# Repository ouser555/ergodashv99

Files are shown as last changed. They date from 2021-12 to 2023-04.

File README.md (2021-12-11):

# ergodashv99
ergodash + v99 trackpoint moudle

pcb & case

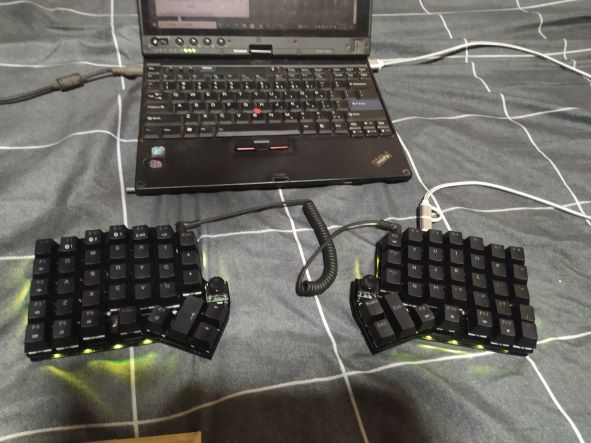
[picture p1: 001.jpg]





mp4 file demo 1: https://imgur.com/L2KnZHe

[IMAGE ALT TEXT HERE)](https://imgur.com/L2KnZHe)

mp4 file demo 2: https://imgur.com/nbIOpWw

[IMAGE ALT TEXT HERE)](https://imgur.com/nbIOpWw)

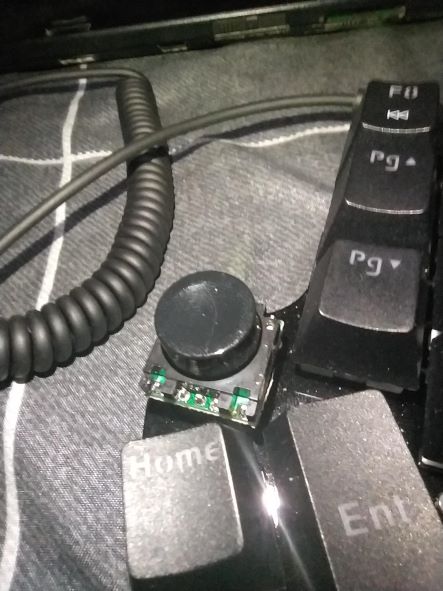
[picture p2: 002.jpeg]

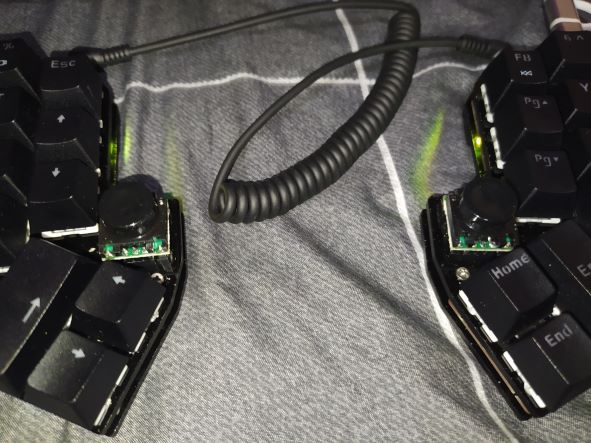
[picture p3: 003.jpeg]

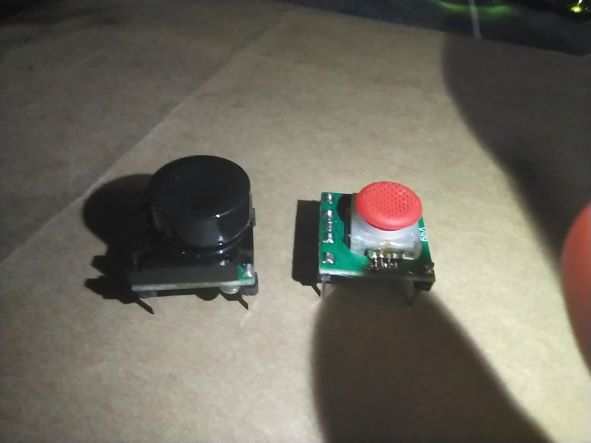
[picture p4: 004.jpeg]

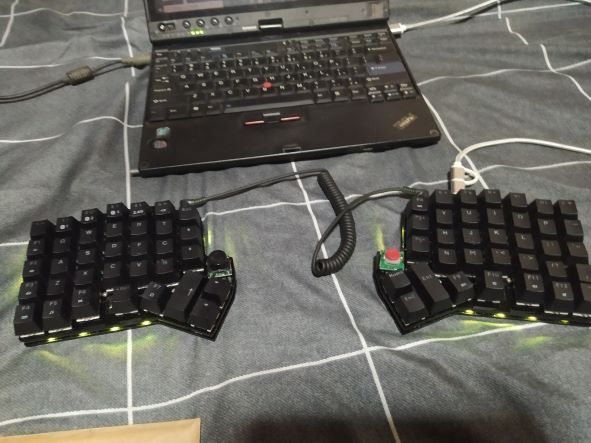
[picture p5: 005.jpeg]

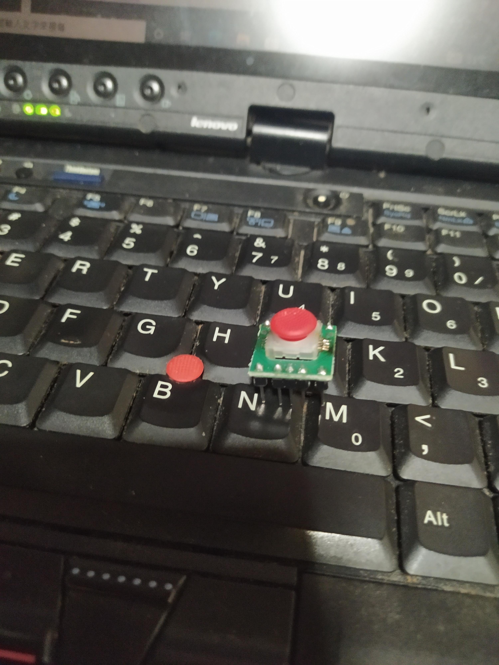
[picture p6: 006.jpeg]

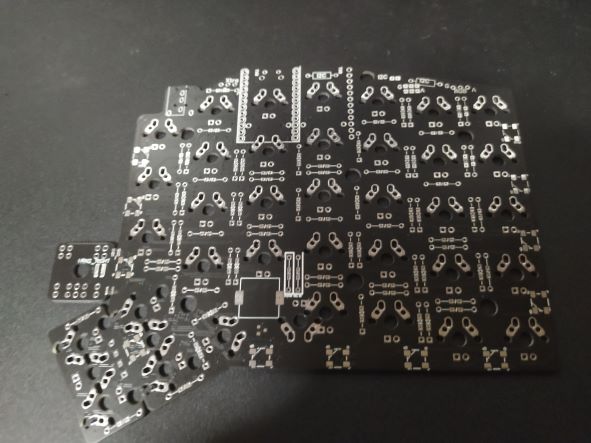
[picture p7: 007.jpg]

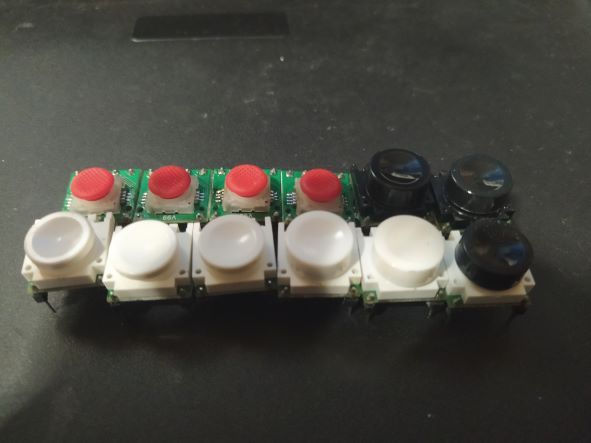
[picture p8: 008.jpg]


## 20211211 土炮增高套件

千辛萬苦找到增高套件協力廠商



組裝完成



演示

VID_20211211_083757

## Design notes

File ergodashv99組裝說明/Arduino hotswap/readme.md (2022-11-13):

## 這裡主要對熱Arduino ProMicro插拔座的安裝方式進行說明。

### 套件裡面有兩組Arduino ProMicro包，附帶三條排針，4Pin的不用理它，用不到。

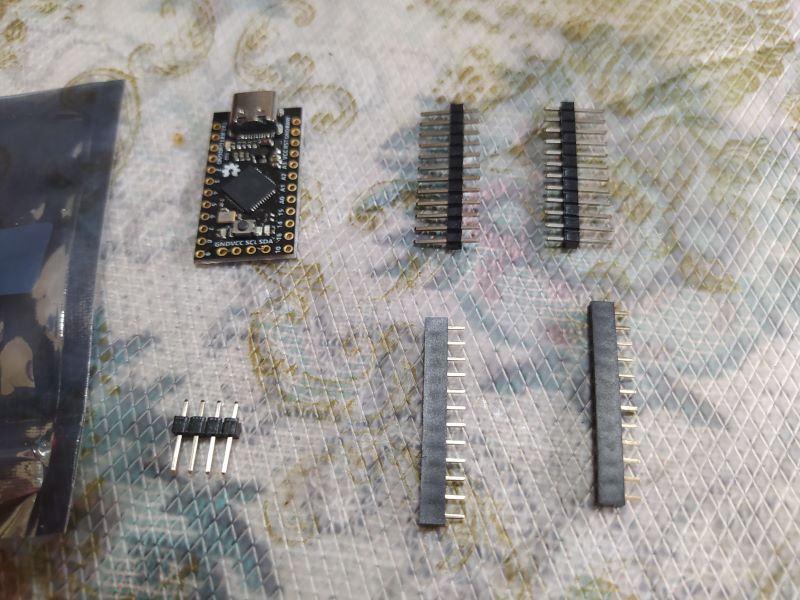
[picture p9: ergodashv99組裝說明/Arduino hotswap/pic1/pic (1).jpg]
  

  如圖所示新增了兩個12Pin的排針座，這是為了讓Arduino ProMicro可以插拔而增加的零件。
 
  這種雙面使用的PCB設計方式，以往經驗會常會有人一不留神把ProMicro焊錯了位置，
  
  導致後來的解焊困難甚至直接放棄治療，所以增加了這個零件來提高容錯率，
  
  未來要維修換軸或者是改藍牙都會更加方便。

### 要讓排針比較容易剪斷，這裡先拿尖嘴鉗把排針短的一端壓入長的那端。
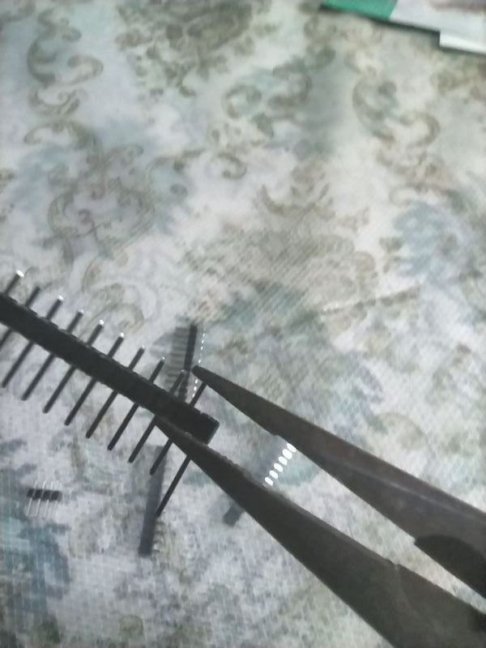
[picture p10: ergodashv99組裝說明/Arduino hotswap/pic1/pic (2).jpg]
  

### 12P壓完如圖所示。一共要壓4條。
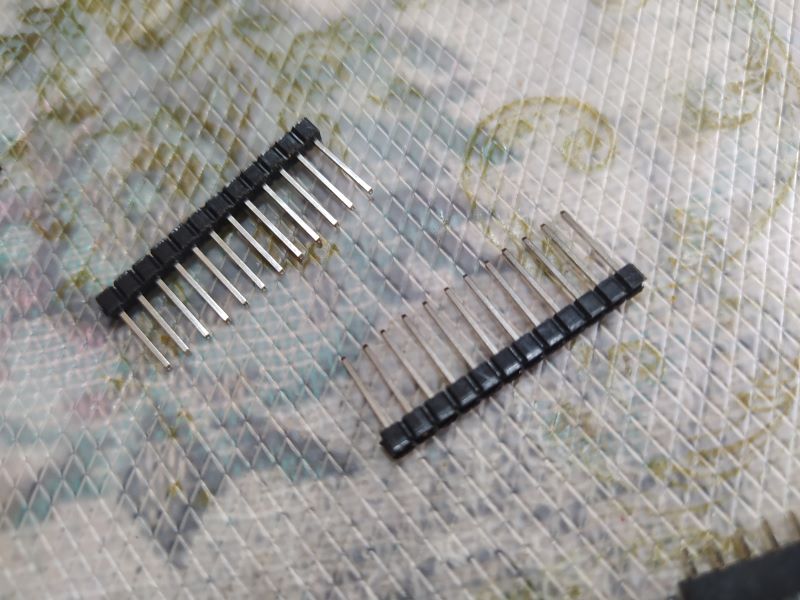
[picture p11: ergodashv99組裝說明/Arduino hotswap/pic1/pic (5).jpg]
  

### 壓好的排針先通過ProMicro後，插入排針座。
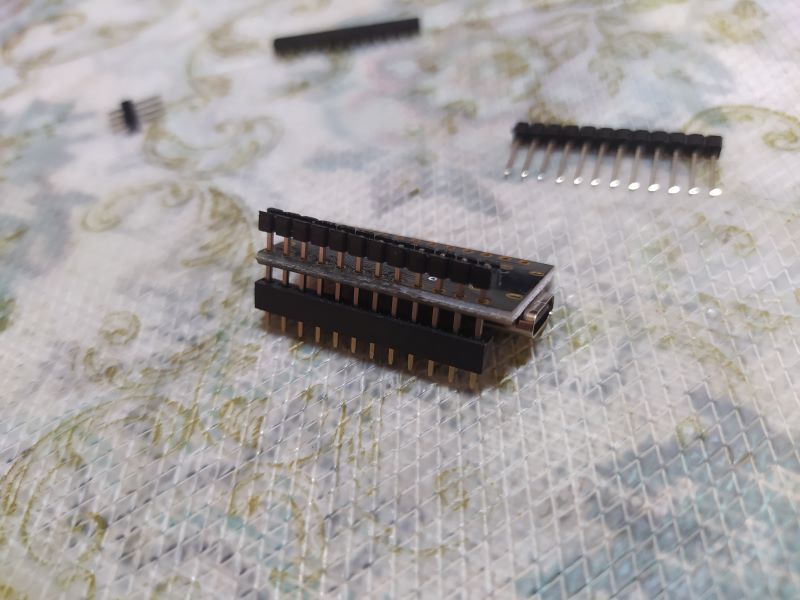
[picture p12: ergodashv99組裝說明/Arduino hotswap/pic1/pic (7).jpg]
  

### 兩邊都先插好。

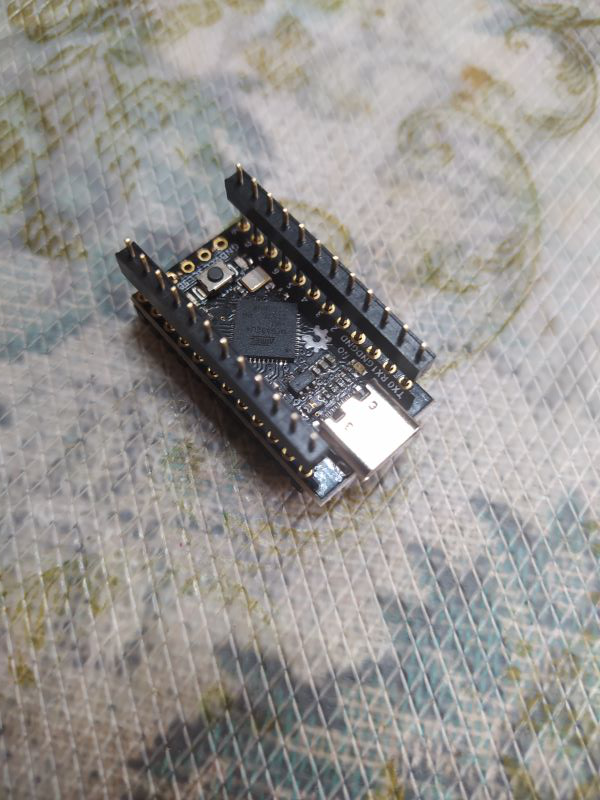
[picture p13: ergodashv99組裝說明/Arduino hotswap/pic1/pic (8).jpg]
  

### 確定鍵盤PCB的零件面，有白框的排針孔。

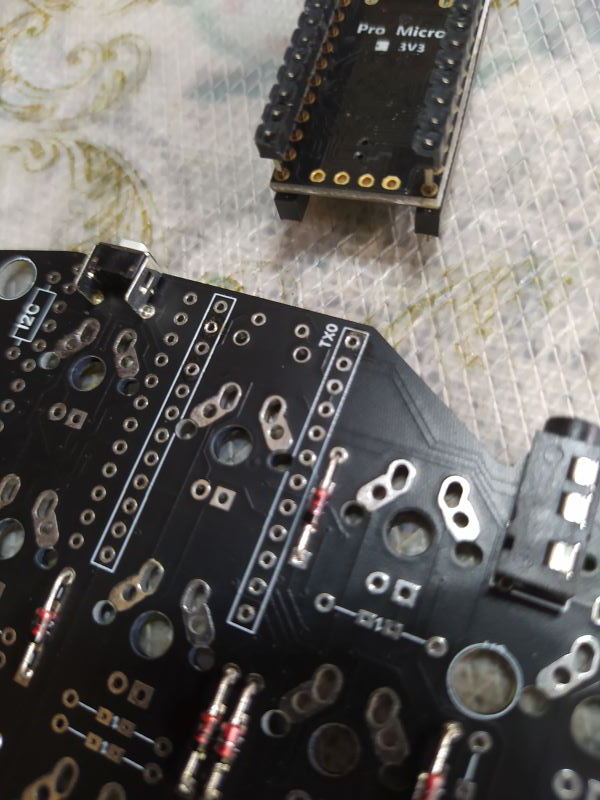
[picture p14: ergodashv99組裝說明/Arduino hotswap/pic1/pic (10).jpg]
  

### 置入，讓PCB貼住下方的排針座，使之間沒有空隙。
  如此ProMicro就成為了一個固定工具，此時先對排針座和鍵盤PCB的部分進行焊接。
  
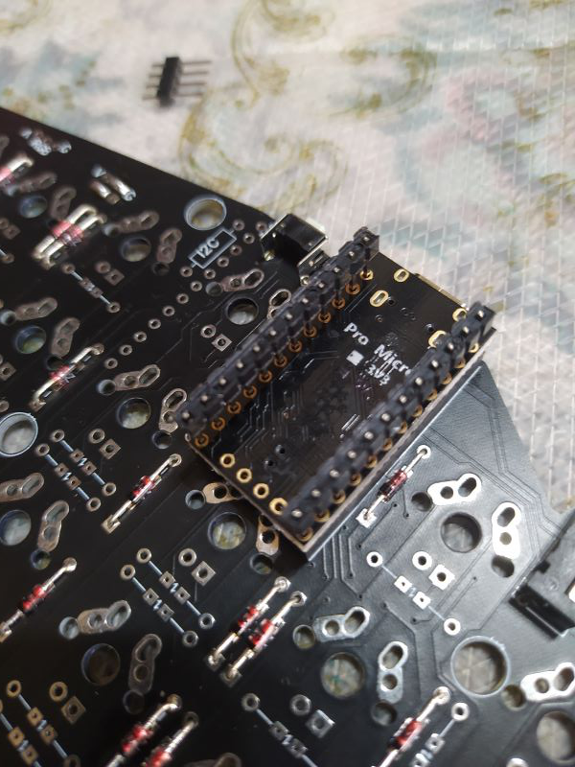
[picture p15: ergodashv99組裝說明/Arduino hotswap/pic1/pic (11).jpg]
  
  
### 焊好如圖。

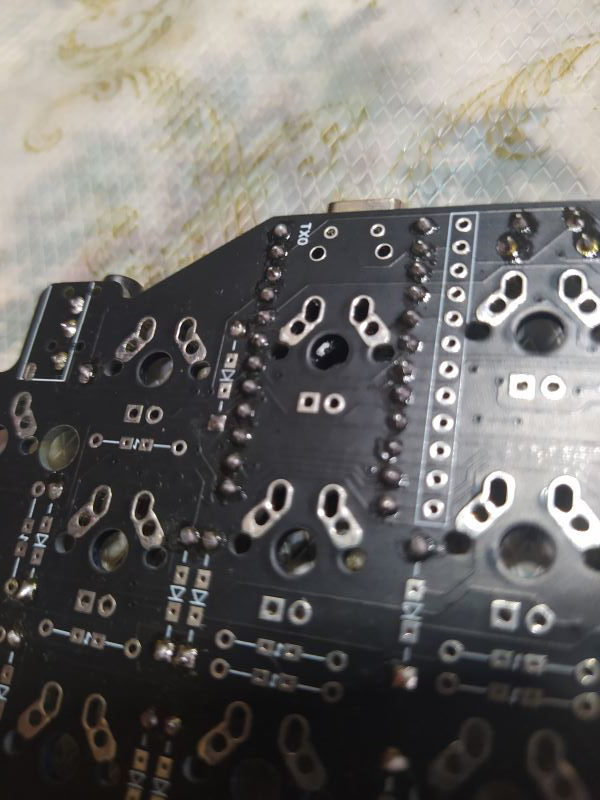
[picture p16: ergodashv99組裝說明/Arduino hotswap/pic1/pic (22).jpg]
  

### 然後就可以焊排針腳和ProMicro的部分。(先焊再剪針腳)
  如果對自己的技術有自信，為了美觀，先剪排針腳再焊接也是可以。(下面失敗案例先看完)
  
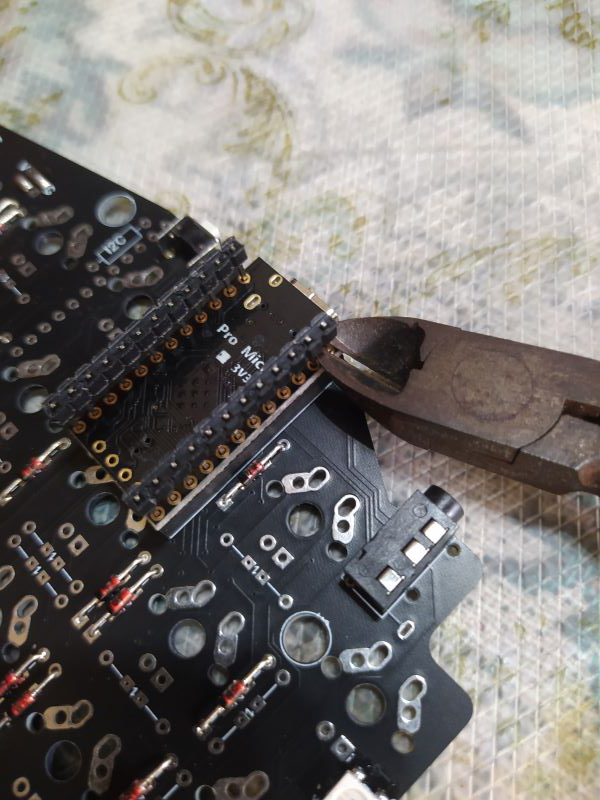
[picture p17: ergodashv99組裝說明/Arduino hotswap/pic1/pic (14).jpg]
  
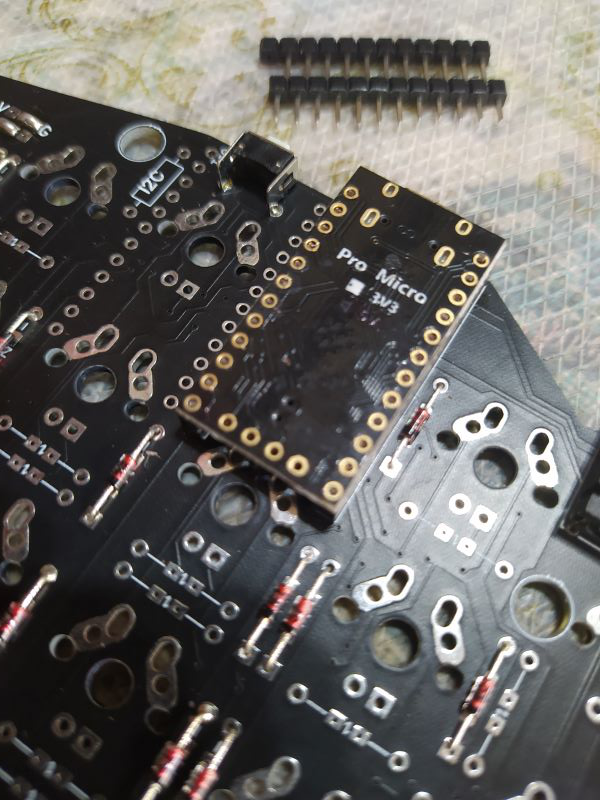
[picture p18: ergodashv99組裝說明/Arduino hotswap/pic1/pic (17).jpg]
  
  
  可以看到剪針腳時，工具或技術不好會把排針拉出來，有的針腳會掉到排針座外面，
  
  後來又必須要重新調整。所以請自行斟酌要先焊或是先剪。
  
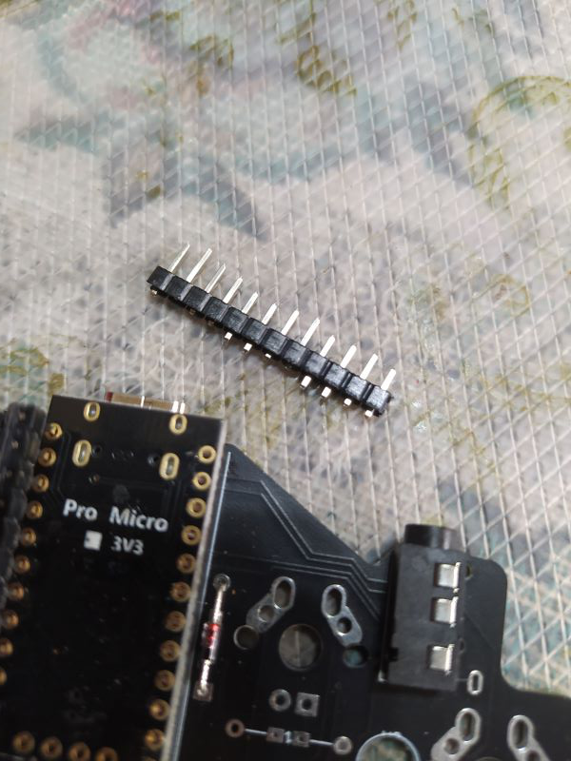
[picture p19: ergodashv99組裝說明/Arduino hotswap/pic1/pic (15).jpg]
  

### 焊好如圖。

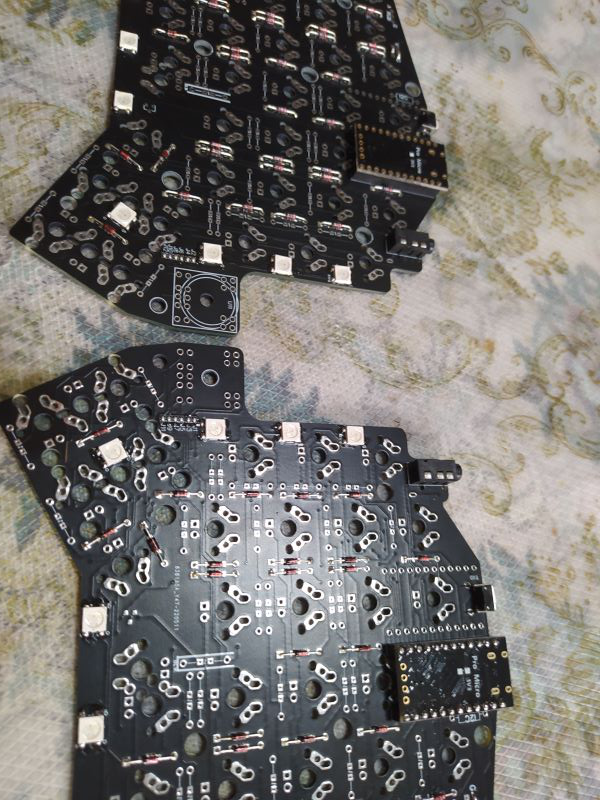
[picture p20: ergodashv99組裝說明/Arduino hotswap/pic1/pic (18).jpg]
  
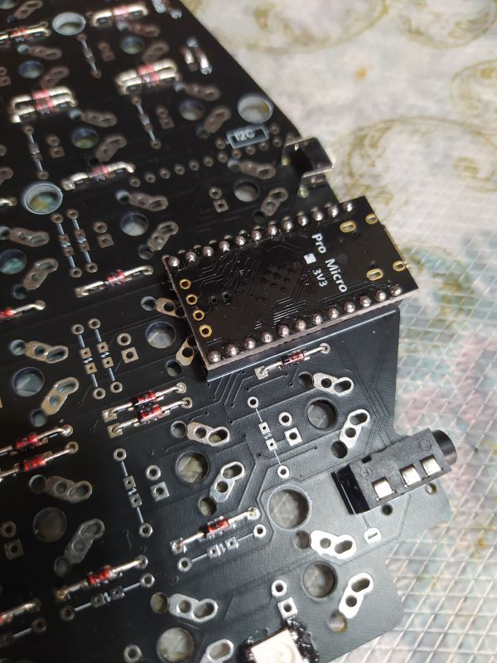
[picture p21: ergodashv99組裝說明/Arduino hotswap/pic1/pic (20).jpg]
  
  
### 拔下來看看，沒問題再插回去。

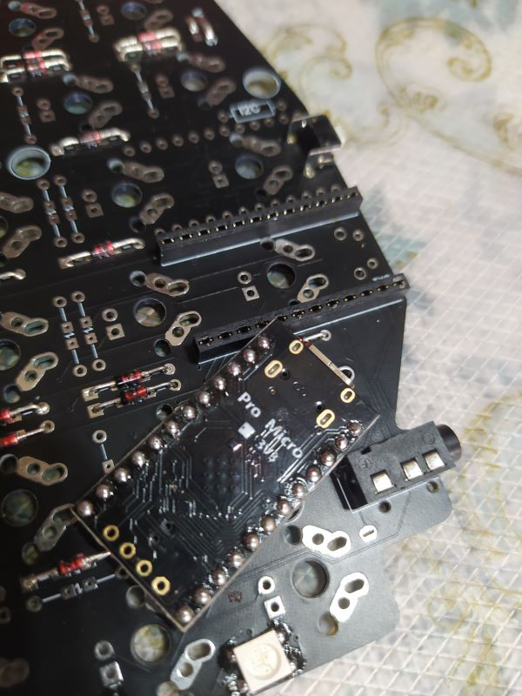
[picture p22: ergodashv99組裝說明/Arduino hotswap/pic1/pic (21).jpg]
  

### 熱插拔元件都是用彈片去夾住針腳的方式設計，為了保持它功能的穩定性，建議不要進行頻繁插拔的動作。

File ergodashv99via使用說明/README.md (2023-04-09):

## ergodashv99 via configuration使用說明

* 最近變動說明
  * 20230409
    * VIA configuartion更新到了3.0.0版。
    * VIA網頁版都會用最新版本，所以有一天網頁版的custom keycode突然不能用了，那就是它對custom keycode最對應的更新了，
      此時若有急用可以先下載程式版的3.0.0應急。  

* 如果要讓trackpoint更容易使用，windows打開設定，滑鼠頁面，設定，這裡提供測試過比較好的參數，使用者也可以依需求自行調整。
  
  滑鼠速度:游標速度:6
  
  滾輪速度:選擇一次要捲動的行數:1(滾輪用這個會比較平滑)
  
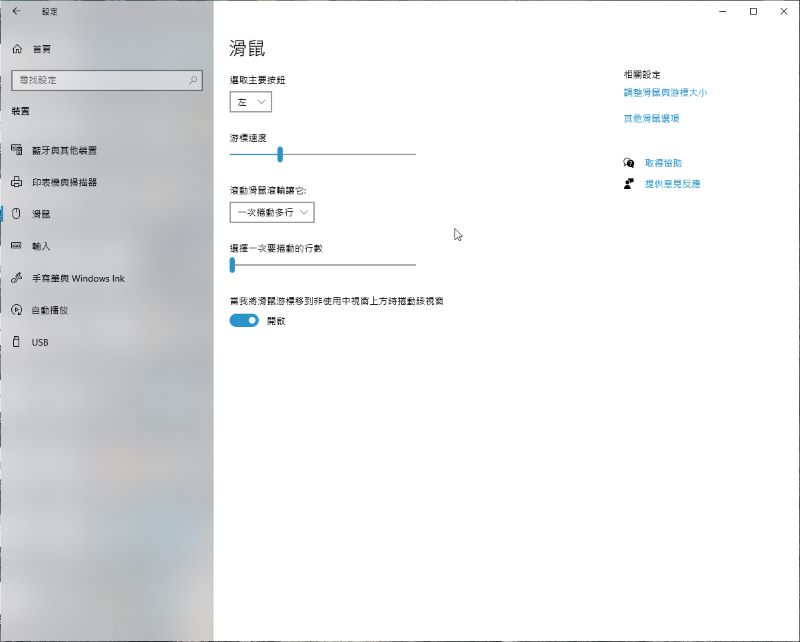
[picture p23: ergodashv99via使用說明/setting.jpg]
  

* 先到 https://caniusevia.com/ 選擇download via下載via configuration。(網頁連結拿掉了)
  * 換這個 https://github.com/the-via/releases/releases/tag/v2.0.5
  * 或更新的 https://github.com/the-via/releases/releases/tag/v2.1.0
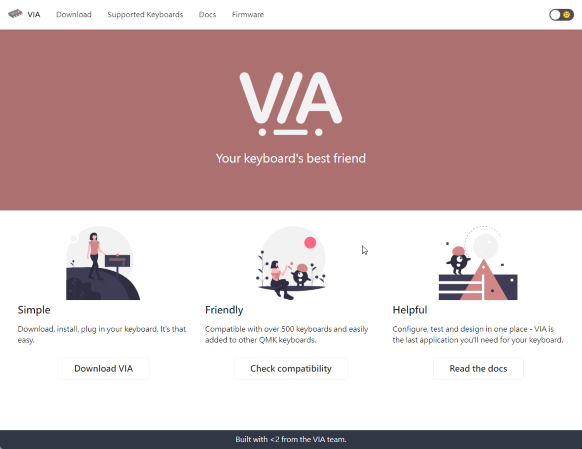
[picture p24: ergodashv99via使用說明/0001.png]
  

* 會連結到github的via頁面，依照作業系統選擇版本，像是windows 10 就選 via-1.3.1-win.exe。

  ~~v1.3.1應該就是最後更新的版本了，以後也不太有可能更新了。~~(最近更新到2.0.5普通使用上沒區別)
  
  舊版的鍵盤firmware要使用via v1.3.1，因為原作者把下載關掉了，這裡備份
  
  https://github.com/ouser555/ergodashv99/releases
  
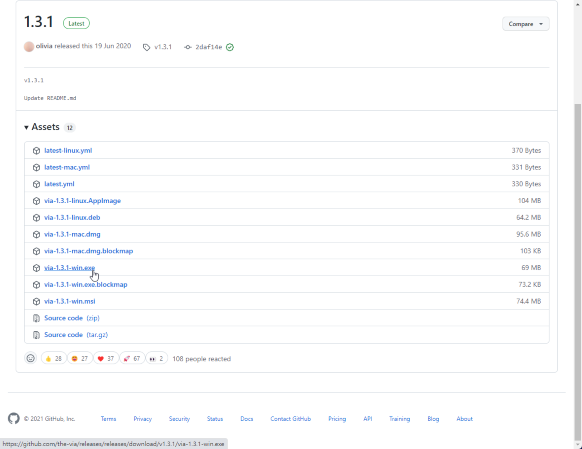
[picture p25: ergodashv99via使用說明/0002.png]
  

* 下載安裝完成後打開via，選上方最右邊的菜單SETTINGS，把第一個選項show design tab打開。
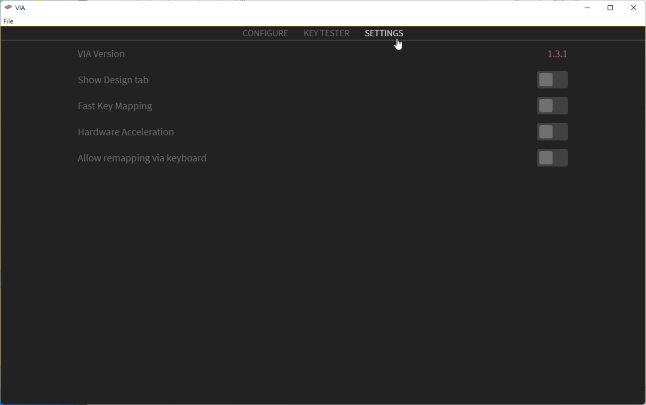
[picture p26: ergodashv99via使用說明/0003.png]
   
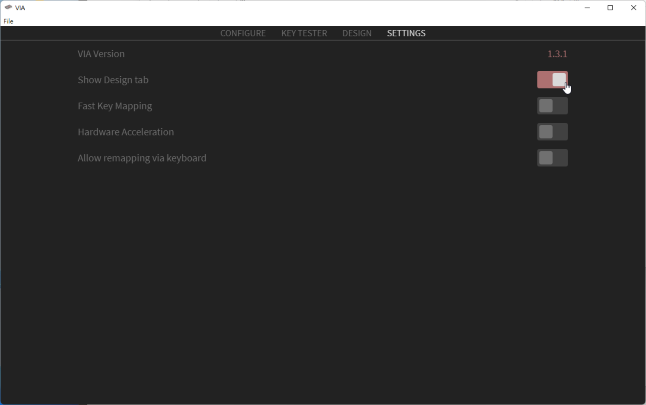
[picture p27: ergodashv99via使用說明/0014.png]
   

* 然後上方的菜單頁會多一個DESIGN，進入這個菜單，點擊Load載入設定檔。
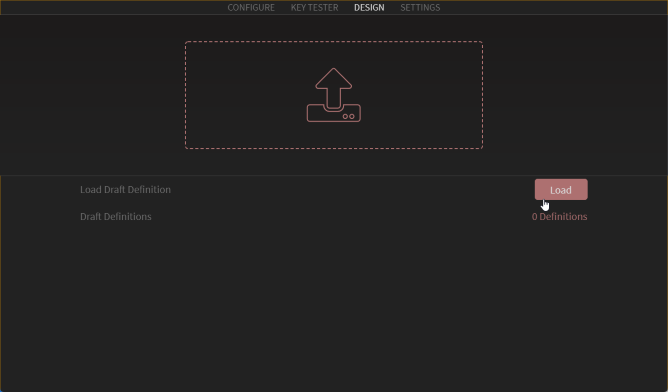
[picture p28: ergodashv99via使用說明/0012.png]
  

* 選擇檔案ErgoDash_4key_2u_inner.json
  (檔案在(檔案在https://git.io/JDxnc)
  
  2022/5/4之後改版
  檔案改選ErgoDash_4key_2u_inner-remap.json
  
  如果你的鍵盤是Ergoknife，
  則是從這裡
  ~~[https://github.com/ouser555/ErgoKnife](https://github.com/ouser555/ErgoKnife)~~
  ~~https://github.com/ouser555/ErgoKnife/blob/main/via%20config/ErgoKnife-20230213.json~~
  https://github.com/ouser555/ErgoKnife/blob/main/via%20config/ErgoKnife-20230303.json
  
  下載 ErgoKnife.json 這個檔案  

  (下載方式:進入github連結後出現檔案列表，先按檔案，然後右邊上方有一個RAW按鈕，右鍵選擇另存連結為...)

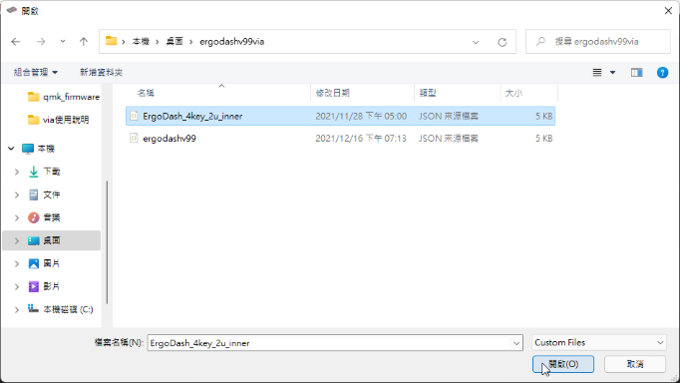
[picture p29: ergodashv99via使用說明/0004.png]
  

* 設定檔載入完成後設這個畫面。

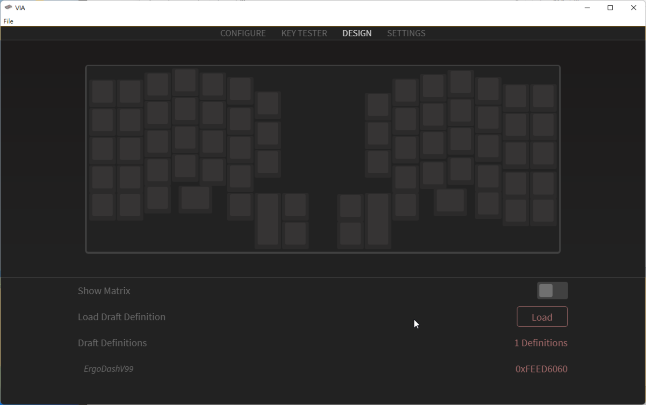
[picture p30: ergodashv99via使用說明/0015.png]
   

* 上方菜單選擇CONFIGURE，如果設定成功的話可以看到正確辨識畫面。
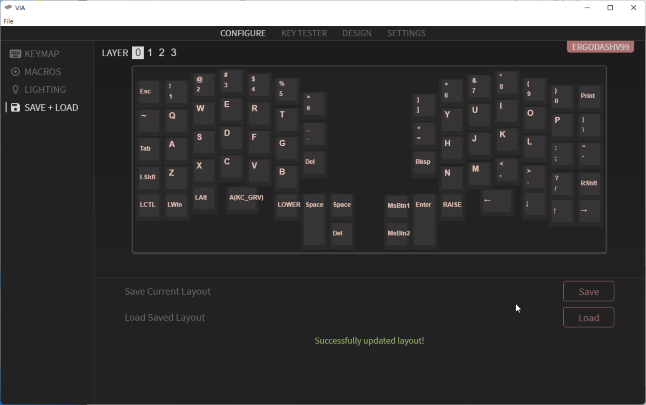
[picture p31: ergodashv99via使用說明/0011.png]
  

* 上方菜單選擇KEYSTESTER，可以測試鍵盤輸入觸發是否正常。
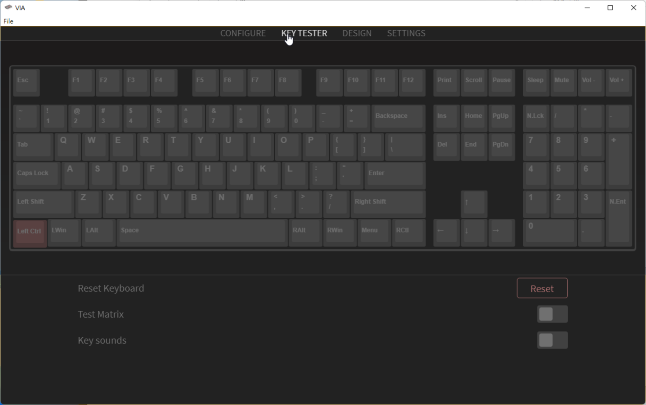
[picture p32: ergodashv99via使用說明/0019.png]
  

* 在這個頁面也可以打開下方的Test Matrix可以更直觀的看見哪個按鍵被觸發。
  
  

* 上方菜單選擇CONFIGURE，這是一般設定KEYMAP的頁面，這個程式的主要功能就是這個。

  選擇左方的SAVE+LOAD，選擇load saved layout
  

* 選擇KEYMAP設定檔 ergodashv99 。
  
  (檔案在https://git.io/JDxnc)
  
  2022/5/4之後改版
  檔案改選ergodashv99-
  
  會依照檔案設定KEYMAP，如果之後有自己的配置也可以用save current layout把keymap保存起來。
  

* 左邊選單回到KEYMAP可以看到重新設定的按鍵映射，LAYER 0 (這裡也只是把右手邊最左邊的兩個鍵改成滑鼠左右鍵而已)。
  
   

* 最上方可以看到這裡原始設定只有四層鍵盤層 LAYER 0 1 2 3，普通狀態都在LAYER 0。
  
  LAYER 0 的名稱是 QWERTY
  
  LAYER 1 的名稱是 LOWER
  
  

  LAYER 2 的名稱是 RAISE
  
  LAYER 3 的名稱是 ADJUST
  
  

* 按著LOWER鍵就可以暫時切到LAYER 1層，此時輸入的鍵都是LAYER 1的配置，放開又回到LAYER 0。
  

* 按著RAISE鍵就可以暫時切到LAYER 2層，此時輸入的鍵都是LAYER 2的配置，放開又回到LAYER 0。
  

* 像是調整背光色相，調整V99的DPI，切換滾輪模式都是設定在LAYER 2，

  所以都是按RAISE鍵切到LAYER 2來操作，

  這就跟筆記型電腦的FN鍵是一樣的道理。
  
  RGB色相是HUE+ HUE-，切換滾輪模式是SCRLS SCRLM，切換DPI是DPIS DPIM，
  
  預設這些鍵都設定在LAYER 2的右下方區域。

* 也可以改這些V99控制鍵的KEYMAP，打開左邊最下方的CUSTOM選單可以看到這些KEYCODE，

  前4顆鍵是4個層，後4顆鍵是v99的DPI和滾輪切換。
  
  4個切換層鍵:
    * LAYER 0 的名稱是 QWERTY
    * LAYER 1 的名稱是 LOWER
    * LAYER 2 的名稱是 RAISE
    * LAYER 3 的名稱是 ADJUST
  
  4個V99功能鍵:
    * SCRLM 右邊的滾輪切換
    * SCRLS 左邊的滾輪切換    
    * DPIM  右邊的DPI切換
    * DPIS  左邊的DPI切換

  

* VIA的KEYMAP設定是跟著安裝VIA的電腦的，

  如果鍵盤要拿到其他電腦操作也是要經過相同的設定才可以轉移KEYMAP，
  
  不然就只能使用預設的KEYMAP。

* 關於VIA的其他設定可以自己測試看看。

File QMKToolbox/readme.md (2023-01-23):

## QMK TOOLBOX燒錄教學

### 1. QMK Toolbox下載

* 到 https://github.com/qmk/qmk_toolbox/releases 下載最新版本，可以選擇install.exe安裝版或是.exe直接執行版，範例選擇直接執行版


### 2. 打開QMK Toolbox



如圖所示做一樣的設定

1.右上的open選擇要使用的燒錄檔

2.Auto-Flash打勾

3.MCU(AVR Only)選擇Atmega32u4



1.將Arduino ProMicro接上電腦的USB。

2.使用聶子或其他可以導電的物體，短接右邊的第2隻腳與第3支腳，觸發硬體RESET，就會開始燒錄。
  * 有些Promico必須要連續觸發兩次RESET，才會開始燒錄。

pro_micro_pinout

3.如果你的promicro已經組裝在鍵盤上，按上方邊緣的reset按鍵，即可觸發硬體RESET，即可開始燒錄。
  * 有些Promico必須要連續觸發兩次RESET，才會開始燒錄。

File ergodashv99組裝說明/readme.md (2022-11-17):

## ergodash v99 組裝說明

## 因為這完整的套件都是經過測試的，所以這套件在設計上應該是不會有奇怪的問題。
## 組裝焊接的工作原本就是依照各人熟悉度不同會有各種不同的結果。
## 如果您對技能不是非常有自信，也可以請有技術的朋友代為進行組裝工作。
## 如果你是第一次組裝類似套件，請詳細參照說明進行操作。
## 如果Arduino板焊接步驟錯誤，排針解焊會非常麻煩，請務必小心。

* !

## 剛開始拿到套件時可以先清點一下零件
* 鍵盤PCB *2
* Arduino ProMicro Type-C *2 (建議先燒好Ergodash程式)
* 排針 2組 *4(Arduino promicro會附)
* V99模組 *2
* 壓克力 *2組 (左右共8片)
* m2*6mm銅柱 *16
* m2*5mm螺絲 *24
* m2*8mm螺絲 *2
* m2*12mm螺絲 *6
* 可插拔針座
  * 12px1 3.5mm *4
  * 2px1 *4
  * 2px2 *4
  * 3px2 *2 
* ~~電阻 * 70(沒有單色LED這個功能，零件不會附上)~~
* 二極體 *70
* ~~LED *70(沒有單色LED這個功能，零件不會附上)~~
* RGB LED *24
* TRRS線 *1 
* !
* ~~已在PCB上先行焊上零件，不在清單中~~
* 其他零件
  * reset鍵 *2
  * TRRS座 *2
  * ~~BACKLIGHT電阻(沒有單色LED這個功能，零件不會附上)~~
  * ~~V99模組排阻(已改成JUMPER了)~~

## 先測試~~自製~~Arduino ProMicro是否可以正常動作

1.到以下網址下載燒錄檔

(舊的版本)
https://github.com/ouser555/qmk_firmware/blob/master/keyboards/ergodash/keymaps/v99v3/hex/ergodash_rev1_v99v3.hex

(新的用這個)
https://github.com/ouser555/qmk_firmware/blob/master/keyboards/ergodash/keymaps/v99v3/hex/ver2/ergodash_rev1_v99v3.hex

滑鼠游標到網頁右邊的RAW上按右鍵，選擇另存連結。(只能這樣下載燒錄檔，用其他方式會下載到無法使用的檔案)

2.燒錄方式
https://github.com/ouser555/ergodashv99/blob/main/QMKToolbox/readme.md



如圖插上USB，電腦是可以辨識到ergodash鍵盤的，確認無誤後再繼續之後的步驟，如果有狀況，請不要繼續，先連絡支援。

兩片Arduino ProMicro都燒同一個燒錄檔。

~~因為通常都會先燒錄程式，測試好再出貨，所以拿到應該是不會有問題的。~~



左右各~~35個電阻~~、35個二極體、12個RGB燈先焊上如圖所示，二極體有方向注意不要弄反。

~~鍵盤PCB上的零件面已經有先焊上部分零件了，應該不會搞錯。(未焊上)~~

RGB LED的缺角pin為接地腳，對應到PCB上的G腳位。



前一步驟零件全焊部好了之後，先放排針上PCB(不要焊)，之後請照步驟執行，不然弄錯會非常非常非常難解決。

排針兩排之外還有2pin，這裡注意都要裝上。

(新版本請看hotswap的說明，若喜歡焊死的方式也可以繼續往下操作)
https://github.com/ouser555/ergodashv99/blob/main/ergodashv99%E7%B5%84%E8%A3%9D%E8%AA%AA%E6%98%8E/Arduino%20hotswap/readme.md



### 把Arduino ProMicro對上，可以平貼，這裡千萬不要不要不要焊上去，只是拿來定位而已。

放Arduino的位置應該不會弄錯，因為另一邊已經放上reset按鍵了，沒辦法放錯誤的那邊。



把鍵盤PCB反過來，進行焊接，這裡只在鍵盤電路板上焊上排針，沒有要焊其他的東西了。



焊好如圖。 然後把Arduino板拿開。



先在壓克力上鎖好6mm銅柱，全部用5mm(較短的)螺絲。

壓克力的保護膜在這個階段可以先把它都撕掉了。



把軸體裝上壓克力，這裡塞的時候請小心不要壓破壓克力。有四顆軸體先不要裝，如圖所示。



這裡有一顆斜放的軸體注意它針腳的位置。檢查所有針腳都沒有彎曲。



全部裝好之後闔上PCB。



正確無誤的話距離如圖所示。



確定固定好沒有縫隙後可以開始焊上軸體。



這裡補充說明，這個鍵盤的拇指區"正方形的位置"可以自由配置"3個按鍵"，只有3個，不能放4個。

請依照圖式選擇要擺放的位置。



把決定好位置剩下4個軸體也焊上。



拿出排針座。
  * 6x1
  * 4x2
  * 2x2



先放上孔位，不要焊上。



拿出trackpoint模組。



插上用來定位。



確定針腳都沒有跑掉。



焊上。



~~這是軸體的LED，雖然有附上，但是程式因為加了trackpoint功能，所以沒有更多的空間了，所以這LED是沒有功能的。要不要焊上看各人。~~

~~這時候不焊上的話，放上Arduino板後就有兩個軸體再也裝不了LED了，這裡可以先考慮好。~~

~~燒原版的ergodash的程式這LED應該是可以動作的，但是還差一個零件，名稱是IRLML6344TRPbF，要讓它動的話請自行再補。~~

(沒有單色LED這個功能，零件不會附上)



現在把Arduino板放上。



這裡會建議焊之前先把針腳先剪了，這樣安裝會比較平整，也比較好看。

要小心針腳飛噴，可以拿張衛生紙揉成球來遮擋。



剪到底。



焊上。



全部焊完看起來是這樣。



接下來是左右手的供電JUMP選擇，依下圖上焊錫。



請依照上圖焊JUMP，下圖只是為了指出JUMP在PCB的位置，JUMP焊法不一樣。



#### Trackpoint正反面的JUMPER，跟放置零件的面是同一面，六個點都焊起來，這因為圖是舊版的PCB，拿到的PCB的JUMPER位置在稍微下方一點。


然後可以先接上電腦的USB，RGB此時應該會被點亮，如果有沒亮的，檢查看看LED有沒有焊對方向。



按按看trackpoint可不可以正常動作，如果不行，也要再檢查上述步驟有沒有什麼地方沒有焊對。

附上關於V99模組的線路圖(X新版PCB腳位配置於下一張圖)



(X新版PCB在Promicro上的腳位，PCB上有標示)
* 改成左邊由上往下

* P2 MISO

* P5 MOSI

* P8 SCLK
* 


檢查動作無誤後，依序放置下蓋的3層壓克力。

下層4顆5mm螺絲，中層1顆8mm螺絲，上層3顆12mm螺絲。



示意圖



最後黏上矽膠腳墊。

這樣就完工了。

幫兩邊鍵盤接上TRSS線，預設是左手鍵盤為主鍵盤，用左手鍵盤接電腦USB即可。

之後就可以到VIA使用說明進行操作
https://github.com/ouser555/ergodashv99/blob/main/ergodashv99via%E4%BD%BF%E7%94%A8%E8%AA%AA%E6%98%8E/README.md

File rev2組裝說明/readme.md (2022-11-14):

## Ergodash rev2 v99 v5 組裝說明 

#### 0.清點零件
* Arduino promicro Type-c模組 x2
* Trackpoint模組 SPI x2
* 12p直排針 x2
* 12p彎排針 x2
* 12p針座3.5mm x4
* 2p針座 x4
* 4p針座 x4
* 6p針座 x2
* PCB x2
* 壓克力殼 x1組(共8片)
* 1N4148 x 70
* RGB LED x 70
* 軸體熱插拔座 x70
* RESET鍵 x2
* TRRS座 x2
* TRRS線 x1
* 銅柱 x 16
* M2x5螺絲 x (8+4)x2=24
* M2x8螺絲 x (1x2)=2
* M2x12螺絲 x (3x2)=6
* 選配
  * 軸體 x70
  * 透光普通ABS鍵帽 x104

#### 1.確定壓克力共有8片，(此為膠膜未撕狀態，正常組裝時膠膜都會撕掉，這裡因為是組裝說明就先不撕了)


#### 2.電路板有兩片，兩片都是一樣的，左右手正反面的PCB是共用的，這裡假定左右手SMD元件都焊好了。


(SMD零件焊好的示意圖，此圖為其他鍵盤。)



#### 3.兩片Arduino Pro Micro Type-C和相應數量的排針。


#### 4.這裡要說明模組的組裝方式有比較不一樣的地方。先拿出彎腳排針。


#### 5.先將排針有限位座的那端插到Pro Micro模組上。


#### 6.壓到底後可以看到排針有凸出來的部分。


#### 7.用尖嘴鉗夾針座和排針凸出的部分，目的是要把排針推壓進去。(這應該會是很輕鬆的操作，如果有吃力的情況，請確認是否有搞錯夾的位置)


#### 8.共12Pin，夾完就像這樣。


#### 9.彎排針有座的單邊變成只有1.6mm的長度，和原本長度的對照圖。


#### 10.這裡先確定一下，排針共有三排，會焊的是零件面的模組有白色的框的兩排，這千萬不可以焊錯，焊錯就要拆焊，會很麻煩。然後就是最上面一個孔是不用的，只要下面12孔。


#### 11.直排針插最中間的那排。和選定的SMD零件面是同一面。


#### 12.從另一面看排針也是在中間，不要讓排針突出來讓他與PCB齊高就好。


#### 13.為的是讓排針座給模組限位，讓它有個自然的空隙。檢查確定位置無誤後這個排針可以先焊起來。


#### 14.在白框的另一邊放上剛剛改的彎排針。確定無誤後可以焊上。


#### 15.可以把模組斜放進去排針座。


#### 16.這是模組要放置的樣子，彎排針是平貼模組的，不剪腳就這樣直接把焊錫溶下去針孔裡。建議可以先焊彎排針的一點然後調整位置讓它可以比較美觀。


#### 17.然後就是直排針，建議先剪排針讓它與模組齊平，然後再焊，這樣比較美觀也比較好剪。這裡順便把側邊按鍵和音源線接頭焊上。


#### 18.這裡有JUMPER要焊
* A.左上三點，焊上面兩點。
* B.左下兩點焊起來。
* C.最右邊兩點焊起來。
* D.中間三點，焊上面兩點



#### 19.Trackpoint正反面的JUMPER，跟焊SMD的零件面同一面，六個點都焊起來，這因為是舊版的PCB，焊點做太小，會比較難焊，新的PCB沒有這個問題。


#### 20.拿出定位板，有些孔位的餘料在切割後沒有拿掉。


#### 21.輕輕推掉即可。


#### 22.用M2*5mm螺絲鎖上M2*6mm銅柱。背面圖。


#### 23.正面圖。


#### 24.闔上PCB。


#### 25.拿出Trackpoint模組和腳座。


#### 26.拿來定位。


#### 27.和孔位對上。


#### 28.背面的樣子。焊上即可。


#### 29.背面的壓克力鎖上。
* 先鎖下方鍵盤4隻長度5mm的螺絲。
* 闔上第二片壓克力，再鎖中間1隻長度8mm的螺絲。
* 闔上最小片的壓克力，最後最高的那層3隻12mm的螺絲。



#### 30.裝上喜歡的軸體鍵帽。

#### 31.接上TRRS線，左邊鍵盤用USB線接電腦即可操作。這裡應該全RGB都會亮起。


* RGB全亮起的示意圖(這圖是無線版的鍵盤)



#### 31.最後可依照VIA使用說明測試鍵盤所有功能。
https://github.com/ouser555/ergodashv99/blob/main/ergodashv99via%E4%BD%BF%E7%94%A8%E8%AA%AA%E6%98%8E/README.md

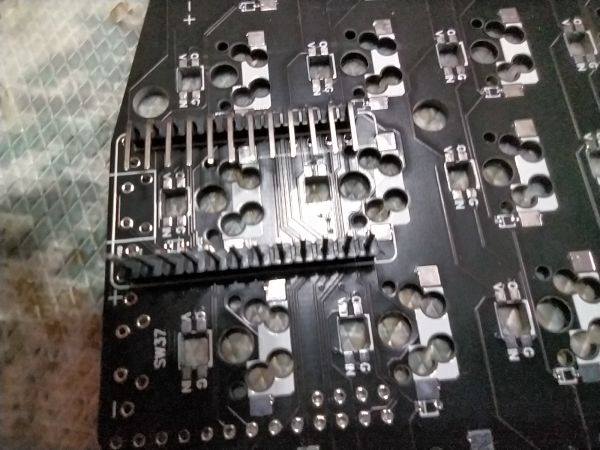
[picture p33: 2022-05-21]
rev2組裝說明/pic/piiic (19).jpg

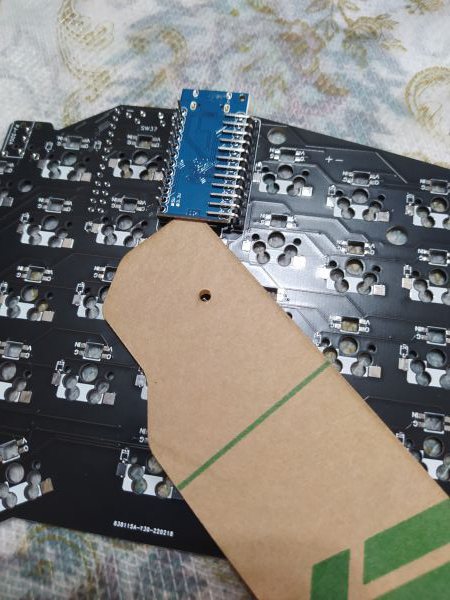
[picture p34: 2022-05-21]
rev2組裝說明/pic/piiic (17).jpg

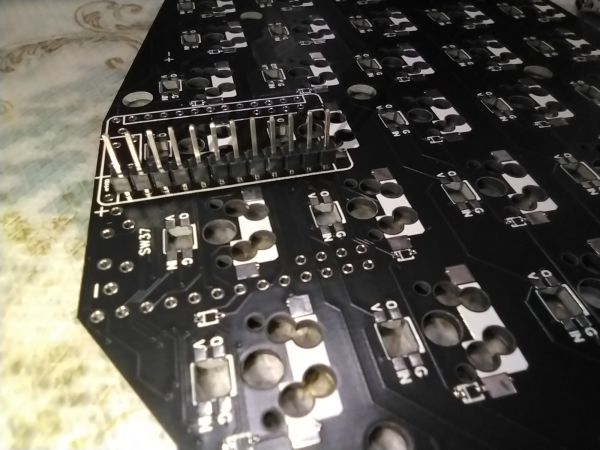
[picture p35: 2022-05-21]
rev2組裝說明/pic/piiic (21).jpg

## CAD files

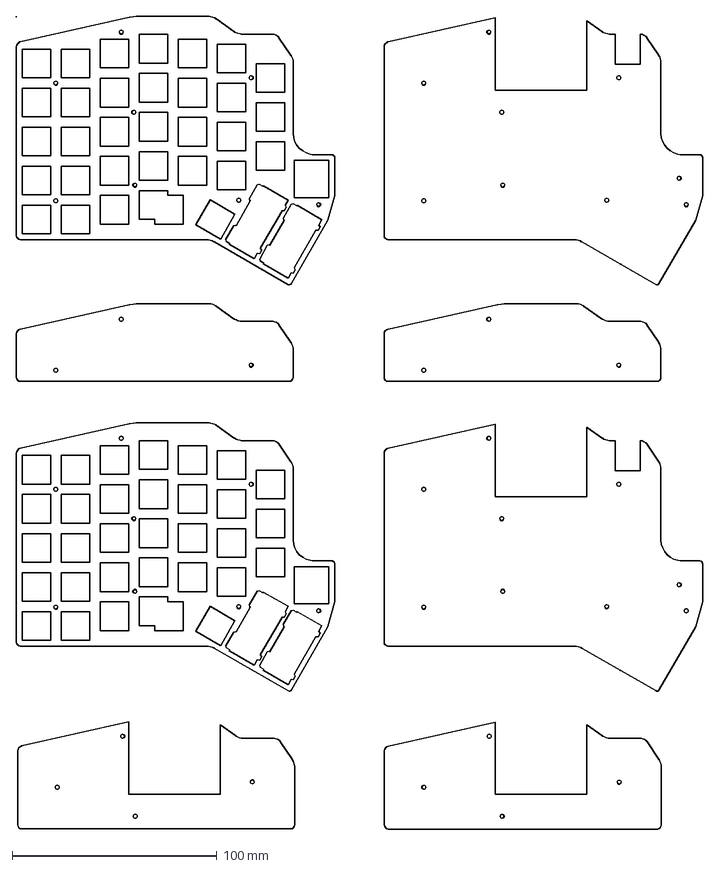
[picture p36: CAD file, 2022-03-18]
ergodashplatedxf/ergodash_v99_3.dxf
334.9 x 396.7 mm
